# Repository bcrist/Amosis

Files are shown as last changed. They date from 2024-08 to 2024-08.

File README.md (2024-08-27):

# Amosis Keyboard

The Amosis is a 40% split keywell board with a Cirque trackpad built into each side.  The case is 3D printed, and features a keywell shape similar to Kinesis or Dactyl keyboards, except with only three rows.

## Controller
This keyboard uses custom controller firmware written from scratch in Zig, and running on an RP2040.

It does not have runtime-swappable layouts or configuration.  Instead, the keyboard layout, layer switching logic, mouse sensitivity, etc. is baked into the firmware, but updating the firmware is just a matter of holding the BOOT button while pressing the RESET button, then dragging a UF2 file to the RPI USB drive.

All of interesting configuration/layout stuff is handed in the [logic.zig](https://github.com/bcrist/Amosis/blob/main/firmware/logic.zig) file.  It should be relatively easy to customize the layout, though if you want to make behavioral changes, you will likely need to know some Zig.

The default layout is based on [Hands Down Gold](https://sites.google.com/alanreiser.com/handsdown#h.j66p50cw2471).  The exact details can be found [here](https://docs.google.com/spreadsheets/d/1Owf2ERAmP1oHp472hNBu8RwOKwRJ6sjyrHRkhDTo6_Y/edit?usp=sharing).

It would probably be possible to use something like QMK with Amosis controllers, but please don't ask me to help with that; I have no interest and little experience with QMK, ZMK, etc.

## Trackpad
Each side of the keyboard integrates a 40mm Cirque GlidePoint trackpad from a Steam Controller.  While Valve stopped producing Steam Controllers years ago, you can still purchase the trackpads from [Mouser](https://www.mouser.com/c/?marcom=118816186), but you will likely need to make some modifications to make this work:

* There are several sizes available; the Steam Controller uses the largest 40mm size (TM40040), but you could use a smaller one if you adjust the case design.
* The retail Circues offer several options for plastic overlays, but the Steam Controller used custom overlays, so you may need to adjust the case design for your chosen overlay style.
* There are (or were) both SPI and I2C versions available.  The Steam Controller only uses SPI, so you'll need to adjust the firmware if you want to use an I2C version (though I think you can change it just by adding/removing a resistor on the Cirque board).  The SPI versions have part numbers TMxx0xx-2024 while the I2C versions have part numbers TMxx0xx-2023.  At time of writing, it appears Mouser no longer carries the I2C version.
* The Steam Controller uses a customized connector pinout that's different than what's documented in the datasheet for the retail version.  You'll need to adjust the schematic board layout to accomodate this.
* An [Alps Haptic Reactor](https://www.mouser.com/ProductDetail/Alps-Alpine/AFT14A903A) force-feedback element is glued to the back of the Steam Controller version and its power is routed through the same FFC cable.  If you buy this separately, you'll have to figure out how you want to connect it to the board.

## Building

Have the controller boards manufactured using the files in the `kicad/gerbers/left/` and `kicad/gerbers/right` folders.

Ensure dependencies are available on your path:
* [Zig](https://ziglang.org/download/)
* [OpenSCAD](https://openscad.org/downloads.html) (2023.03.18 or newer; scroll down to "Development Snapshots")

Adjust the keymapping and layer logic as you like, then run `zig build`.

3D print a case using `zig-out/bin/left.stl` and `zig-out/bin/right.stl`.

Flash the `zig-out/bin/firmware.uf2` and to both controllers (the same file can be used for both sides because the firmware will detect which side it is at boot).

### Wiring
The 3 row signals are driven to 3.3V when scanning a row, and 0V when not scanning that row.
The 7 column signals are read as inputs with weak pull-downs, and treat a high value as indicating that a switch is pressed.
Therefore, there are 2 possible ways to wire the diode/switch matrix that will work:
* Diodes between the row signals and the switches, with a common anode for each row.
* Diodes between the column signals and the switches, with a common cathode for each column.

Note the line on diode packages indicates the cathode side.
Also note while the schematics list a schottky diode part number, any general purpose diodes will work fine for the matrix, e.g. 1N914/1N4148, 1N4001, etc.

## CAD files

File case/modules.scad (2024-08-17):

module edge_sphere() {
    sphere(edge_radius);
}

module edge_capsule() {
    hull() {
        translate([0, 0, -edge_radius]) sphere(edge_radius);
        translate([0, 0, -plate_thickness + edge_radius]) sphere(edge_radius);
    }
}

module cherry_mx_plate(width_u = 1, height_u = 1) {
    u = 19.05;
    width = width_u * u - switch_plate_inset;
    height = height_u * u - switch_plate_inset;
    clip_thickness = 1.5;
    clip_inset = 0.25;
    clip_width = 5;
    hole_size = 14.2;
    nub_length = 3.5;
    nub_radius = 0.8;

    horiz_edge();
    rotate([0, 0, 180]) horiz_edge();
    
    vert_edge();
    rotate([0, 0, 180]) vert_edge();

    children();
    
    module vert_edge() {
        translate([-width/2, -height/2]) {
            hull() {
                translate([0, 0, -edge_radius]) sphere(edge_radius);
                translate([0, 0, -plate_thickness + edge_radius]) sphere(edge_radius);
                translate([width, 0, -edge_radius]) sphere(edge_radius);
                translate([width, 0, -plate_thickness + edge_radius]) sphere(edge_radius);
            }
            translate([0, 0, -clip_thickness]) cube([width, height/2 - hole_size/2, clip_thickness]);
            translate([0, 0, -plate_thickness]) {
                cube([width, height/2 - hole_size/2 - clip_inset, plate_thickness]);
                cube([width/2 - clip_width/2, height/2 - hole_size/2, plate_thickness]);
                translate([width/2 + clip_width/2, 0]) cube([width/2 - clip_width/2, height/2 - hole_size/2, plate_thickness]);
            }
        }
    }
    
    module horiz_edge() {
        translate([-width/2, -height/2]) {
            hull() {
                translate([0, 0, -edge_radius]) sphere(edge_radius);
                translate([0, 0, -plate_thickness + edge_radius]) sphere(edge_radius);
                translate([0, height, -edge_radius]) sphere(edge_radius);
                translate([0, height, -plate_thickness + edge_radius]) sphere(edge_radius);
            }
            translate([0, 0, -plate_thickness]) cube([width/2 - hole_size/2, height, plate_thickness]);
        }
        // nub
        translate([0, 0, -plate_thickness]) hull() {
            translate([-hole_size/2, 0, plate_thickness/2]) cube([0.01, nub_length, plate_thickness], center=true);
            translate([-hole_size/2, 0, nub_radius]) rotate([90, 0, 0]) cylinder(nub_length, nub_radius, nub_radius, center=true);
        }
    }
}

module cherry_mx() {
    stem_height = 4;
    stem_thickness_x = 1.35;
    stem_thickness_y = 1.15;
    stem_width = 4.5;

    stem_base_width = 7.2;
    stem_base_height = 5.6;
    stem_base_offset = 0.4;

    cover_top = 10.2;
    cover_bottom = 14.6;
    cover_height = 5.3;

    foot_height = 0.8;
    foot_width = 15.6;

    base = 14;
    base_height = 5.5;
    base_taper = 1;
    plate_height = 2.2;

    translate([0, 0, cover_height + foot_height + stem_base_offset]) {
        children();
    }

    translate([0, 0, stem_height + cover_height + foot_height])
    {
        color("cyan"){
            translate([0, 0, -stem_height / 2]) {
                cube([stem_thickness_x, stem_width, stem_height], center=true);
                cube([stem_width, stem_thickness_y, stem_height], center=true);
            }
            translate([0, 0, -stem_height - 1 + stem_base_offset]) {
                cube([stem_base_width, stem_base_height, 2], center=true);
            }
        }
        
        color("grey") translate([0, 0, -stem_height]) {		
            hull(){
                cube([cover_top, cover_top, 0.1], center=true);
                translate([0, 0, -cover_height]) cube([cover_bottom, cover_bottom, 0.1], center=true);
            }
            
            translate([0, 0, -cover_height]) {
                hull(){
                    translate([0, 0, -plate_height/2]) cube([base, base, plate_height], center=true);
                    translate([0, 0, -base_height]) cube([base - base_taper, base - base_taper, 0.1], center=true);
                }

                translate([0, 0, -foot_height/2]) cube([foot_width, foot_width, foot_height], center=true);
                translate([0, 0, -foot_height]) difference(){
                    hull(){
                        translate([0, 0, -1.4]) cube([3.5, 14, 0.1], center=true);
                        translate([0, 0, -2])   cube([3.5, 14.75, 0.1], center=true);
                        translate([0, 0, -2.5]) cube([3.5, 14, 0.1], center=true);
                    }
                    translate([0, 0, -1.5]) cube([2, 20, 4], center=true);
                }
            }
        }
    }
}

module keycap_sa(raw_row = 3, width_u = 1, height_u = 1) {
    row = 3 - abs(3 - raw_row);
    base_height = 12.6;
    sa_radius = 33.3;
    row_offset = 4;
    dy = row_offset * (3 - raw_row);
    u = 19.05;
    width = width_u * u;
    height = height_u * u;
    color("#99f") translate([0, -dy, -row + 1]) difference() {
        intersection() {
            union() {
                translate([sa_radius - width/2, height/2 + dy, 0])   rotate([90,0,0]) cylinder(h = height, r = sa_radius);
                translate([sa_radius + width/2, dy, sa_radius/2]) cube([width*2, height, sa_radius], center=true);
            }
            union() {
                translate([-width/2, sa_radius - height/2 + dy, 0]) rotate([90,0,90])  cylinder(h = width, r = sa_radius);
                translate([0, sa_radius + height/2 + dy, sa_radius/2]) cube([width, height*2, sa_radius], center=true);
            }
            union() {
                translate([-sa_radius + width/2, -height/2 + dy, 0])   rotate([90,0,180]) cylinder(h = height, r = sa_radius);
                translate([-sa_radius - width/2, dy, sa_radius/2]) cube([width*2, height, sa_radius], center=true);
            }
            union() {
                translate([width/2, -sa_radius + height/2 + dy, 0]) rotate([90,0,270])  cylinder(h = width, r = sa_radius);
                translate([0, -sa_radius - height/2 + dy, sa_radius/2]) cube([width, height*2, sa_radius], center=true);
            }
        }
        scale([width_u, height_u, 1]) {
            translate([0, 0, base_height + sa_radius]) sphere(r = sa_radius);
            translate([0, 0, -sa_radius + row - 1]) cube(sa_radius * 2, center=true);
        }
    }
}

cirque_outer_diameter = 42.8;
cirque_inner_diameter = 35;
cirque_inset_depth = 2;
cirque_border_width = 1;
cirque_base_thickness = 30;
cirque_edge_radius = 8;

module half_cirque_plate() {
    total_depth = cirque_base_thickness + cirque_inset_depth;
    outer_radius = cirque_outer_diameter / 2;
    
    translate([0, 0, -total_depth]) {
        intersection() {
            mask_side_length = 2 * (outer_radius + cirque_border_width + cirque_edge_radius);
            translate([0, mask_side_length/2, 0]) cube([mask_side_length, mask_side_length, total_depth * 2], center = true);
            minkowski() {
                cylinder(h = total_depth - cirque_edge_radius, r = outer_radius + cirque_border_width, $fn = 180);
                sphere(cirque_edge_radius, $fn = 90);
            }
        }
    }
}

module cirque_plate() {
    total_depth = cirque_base_thickness + cirque_inset_depth;
    outer_radius = cirque_outer_diameter / 2;
    
    translate([0, 0, -total_depth]) {
        minkowski() {
            cylinder(h = total_depth - cirque_edge_radius, r = outer_radius + cirque_border_width, $fn = 180);
            sphere(cirque_edge_radius, $fn = 90);
        }
    }
}

module cirque_plate_holes() {
    total_depth = cirque_base_thickness + cirque_inset_depth;
    outer_radius = cirque_outer_diameter / 2;
    inner_radius = cirque_inner_diameter / 2;
    
    translate([0, 0, -total_depth]) {
        cylinder(h = 3*total_depth, r = inner_radius, center = true);
        translate([0, 0, cirque_base_thickness]) cylinder(h = total_depth, r = outer_radius, $fn = 180);
    }
}

module cable_guide() {
    minkowski() {
        cube([1, 40, 10], center=true);
        sphere(5);
    }
}

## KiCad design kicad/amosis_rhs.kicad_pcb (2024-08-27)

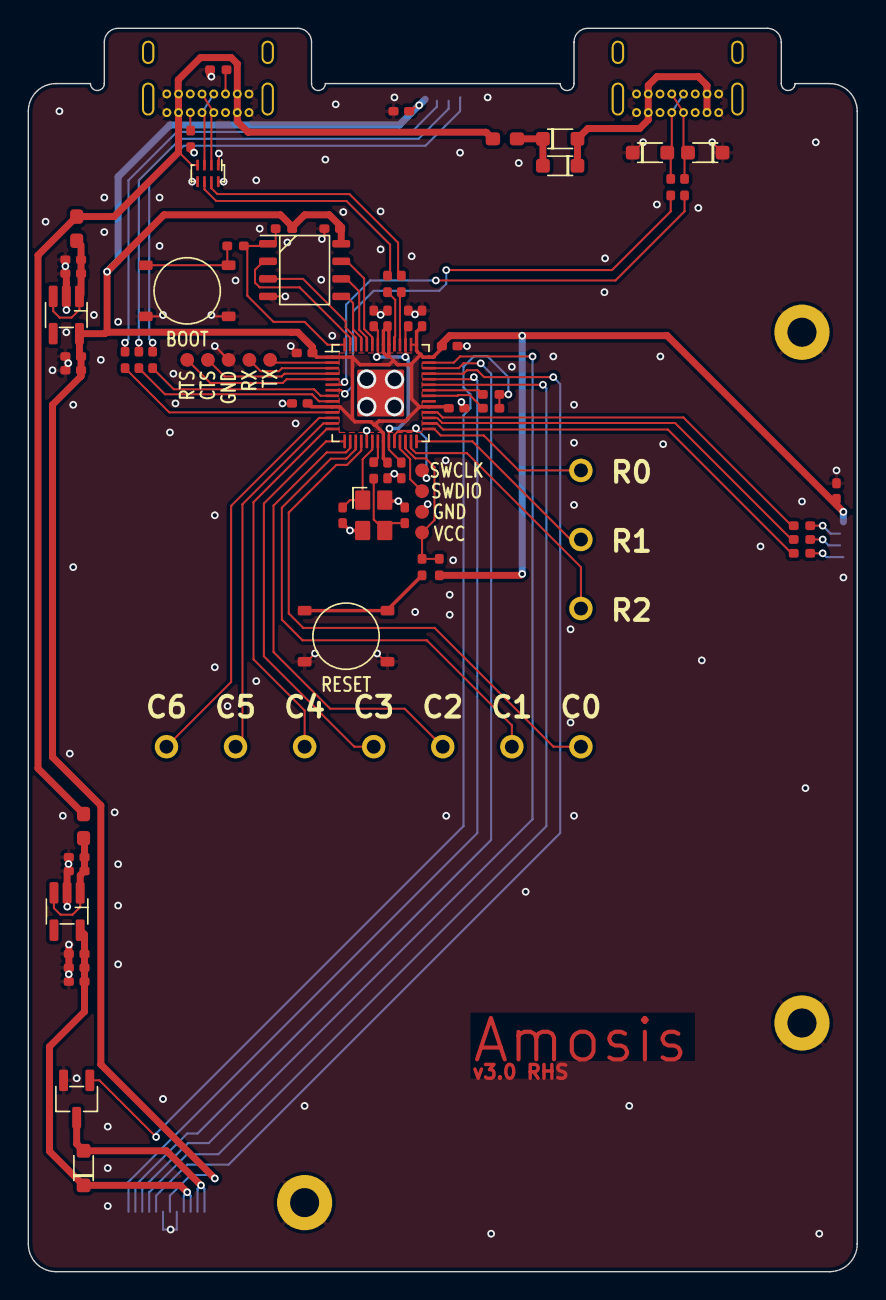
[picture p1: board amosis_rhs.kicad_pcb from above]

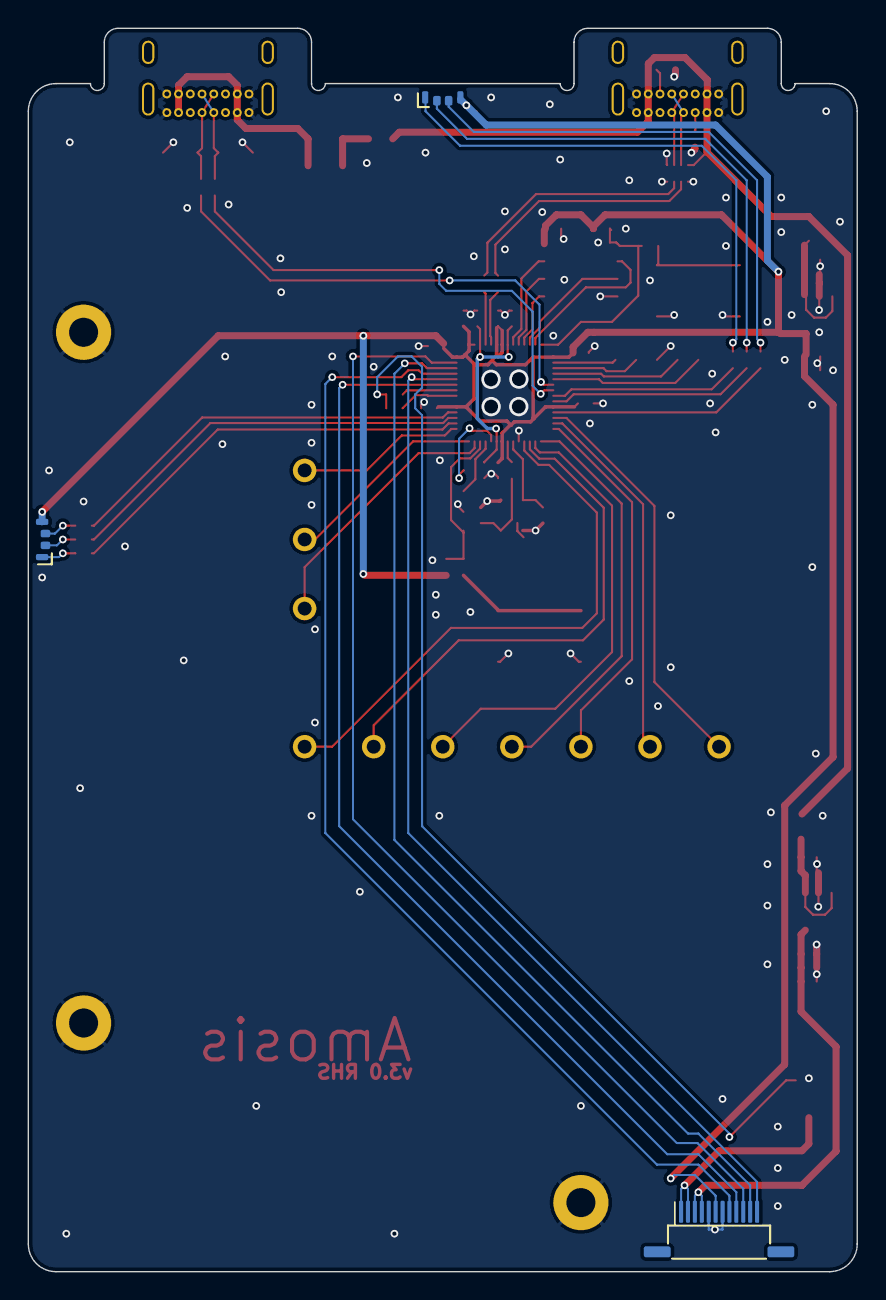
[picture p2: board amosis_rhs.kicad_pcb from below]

Board: 2 copper layers, 60.0 x 90.0 mm, 87 parts (5 on the bottom side), 70 nets.

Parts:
C1, C4, C5, C8, C10, C17: 1; C_0402
C2, C3, C6, C7, C11, C12, C13, C14, C15, C16, C18, C19, C20, C23, C24: 0.1; C_0402
C9: 10; C_0402
C21, C22: 14p; C_0402
COL_{0}1: COL_{0}; PinHeader_1x01
COL_{1}1: COL_{1}; PinHeader_1x01
COL_{2}1: COL_{2}; PinHeader_1x01
COL_{3}1: COL_{3}; PinHeader_1x01
COL_{4}1: COL_{4}; PinHeader_1x01
COL_{5}1: COL_{5}; PinHeader_1x01
COL_{6}1: ROW_{0}; PinHeader_1x01
D22, D23: CUS520; SOD-323
D24: ECMF02-4CMX8; DFN-8-2.5x1.2-P0.45
D25, D26: DESD5V0U1BA; SOD-323
D27, D28: LED_BGRA; Harvatek-B3233GBR-20
D29: MMBD914LT1; SOD-323
FB1, FB2, FB3: PE-0603FB121ST; L_0603
J1, J2: USB-C-16; USB_GCT_USB4085-FG-A
J3: VALVE; FFC_GCT_FFC2B28-12-G
M1, M2, M3: GND; MountingHole_M2_Pad
Q1: MMBT3904; SOT-23
R1, R13: 10K; R_0402
R2, R12, R16: 1K; R_0402
R3, R4: 50; R_0402
R5, R8: 27.4; R_0402
R6, R7, R18: 5.1K; R_0402
R9, R14: 120; R_0402
R10, R11, R15, R17: 10; R_0402
R19: 2.2K; R_0402
ROW_{0}1: ROW_{1}; PinHeader_1x01
ROW_{1}1: ROW_{2}; PinHeader_1x01
ROW_{2}1: ROW_{3}; PinHeader_1x01
SW22: RESET; SW_CK_PTS526
SW23: BOOT; SW_CK_PTS526
U1: MIC5504-3.3YM5; SOT-23-5
U2: MIC5504-2.5YM5; SOT-23-5
U3: RP2040; QFN-56-EP-7x7-P0.4
U4: ZD25Q80CT; SOP-8-4.9x3.9-P1.27
X1: RH100-12.000-12-1010-X-TR-NS2
tCTS1: CTS; TestPoint
tGND1, tGND2: GND; TestPoint
tRTS1: RTS; TestPoint
tRUN1: VCC; TestPoint
tRX1: RX; TestPoint
tSWCLK1: SWCLK; TestPoint
tSWDIO1: SWDIO; TestPoint
tTX1: TX; TestPoint

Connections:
+2V5: C7.1, C8.1, C9.1, D29.1 (K), J3.3, J3.4, U2.5 (VOUT)
/COL_{0}: COL_{0}1.1, U3.18 (P15)
/COL_{1}: COL_{1}1.1, U3.17 (P14)
/COL_{2}: COL_{2}1.1, U3.16 (P13)
/COL_{3}: COL_{3}1.1, U3.15 (P12)
/COL_{4}: COL_{4}1.1, U3.14 (P11)
/COL_{5}: COL_{5}1.1, U3.13 (P10)
/COL_{6}: COL_{6}1.1, U3.12 (P9)
/DR: J3.9, U3.37 (P25)
/LINK_RX: R3.2, U3.7 (P5)
/LINK_TX: R4.1, U3.6 (P4)
/MISO: J3.11, U3.40 (P28/A2)
/MOSI: J3.8, U3.39 (P27/A1)
/ROW_{0}: ROW_{0}1.1, U3.29 (P18)
/ROW_{1}: ROW_{1}1.1, U3.28 (P17)
/ROW_{2}: ROW_{2}1.1, U3.27 (P16)
/SCLK: J3.12, U3.38 (P26/A0)
/SS: J3.10, U3.41 (P29/A3)
GND: C1.2, C2.2, C3.2, C4.2, C5.2, C6.2, C7.2, C8.2, C9.2, C10.2, C11.2, C12.2, C13.2, C14.2, C15.2, C16.2, C17.2, C18.2, C19.2, C20.2, C21.2, C22.2, C23.2, C24.2, D24.1, D24.5, D24.8, D25.1 (A1), D26.1 (A1), J1.A1 (GND), J1.A12 (GND), J1.B1 (GND), J1.B12 (GND), J2.A1 (GND), J2.A12 (GND), J2.B1 (GND), J2.B12 (GND), J3.5, J3.7, M1.1, M2.1, M3.1, Q1.2 (E), R6.2, R7.2, SW22.3, SW22.4, SW23.3, SW23.4, U1.2 (GND), U2.2 (GND), U3.19 (GND), U3.EP (GND), U4.4 (GND), X1.2, X1.4, tGND1.1, tGND2.1
unnamed: C22.1, R12.2, X1.3
unnamed: D22.2 (A), D23.1 (K), FB3.2
unnamed: D22.1 (K), D23.2 (A), J1.A4 (V_{BUS}), J1.A9 (V_{BUS}), J1.B4 (V_{BUS}), J1.B9 (V_{BUS})
unnamed: D24.6, R5.2
unnamed: D24.7, R8.1
unnamed: D25.2 (A2), J1.A6 (D+1), J1.B6 (D+2), R3.1
unnamed: D26.2 (A2), J1.A7 (D-1), J1.B7 (D-2), R4.2
unnamed: D27.1 (BK), R9.2
unnamed: D27.2 (GK), R10.2
unnamed: D27.3 (RK), R11.2
unnamed: D28.1 (BK), R14.2
unnamed: D28.2 (GK), R15.2
unnamed: D28.3 (RK), R17.2
unnamed: D29.2 (A), J3.1, J3.2, Q1.3 (C)
unnamed: J2.A5 (CC1), R6.1
unnamed: J2.B5 (CC2), R7.1
unnamed: D24.3, J2.A6 (D+1), J2.B6 (D+2)
unnamed: D24.2, J2.A7 (D-1), J2.B7 (D-2)
unnamed: Q1.1 (B), R18.2, R19.2
unnamed: R2.2, SW22.1, SW22.2
unnamed: R16.2, SW23.1, SW23.2
unnamed: C1.1, C2.1, FB1.2, U1.1 (VIN), U1.3 (EN)
unnamed: C5.1, C6.1, FB2.2, U2.1 (VIN), U2.3 (EN)
unnamed: U3.2 (P0), tTX1.1
unnamed: U3.3 (P1), tRX1.1
unnamed: U3.4 (P2), tCTS1.1
unnamed: U3.5 (P3), tRTS1.1
unnamed: R9.1, U3.8 (P6)
unnamed: R10.1, U3.9 (P7)
unnamed: R11.1, U3.11 (P8)
unnamed: R14.1, U3.30 (P19)
unnamed: R15.1, U3.31 (P20)
unnamed: R17.1, U3.32 (P21)
unnamed: R18.1, U3.35 (P23)
unnamed: R19.1, U3.36 (P24)
unnamed: U3.52 (QSPI_{CLK}), U4.6 (CLK)
unnamed: U3.53 (QSPI_{SD0}), U4.5 (D0)
unnamed: U3.55 (QSPI_{SD1}), U4.2 (D1)
unnamed: U3.54 (QSPI_{SD2}), U4.3 (D2)
unnamed: U3.51 (QSPI_{SD3}), U4.7 (D3)
unnamed: R13.2, R16.1, U3.56 (QSPI_{~SS}), U4.1 (~CS)
unnamed: R1.2, R2.1, U3.26 (RUN), tRUN1.1
unnamed: U3.24 (SWCLK), tSWCLK1.1
unnamed: U3.25 (SWDIO), tSWDIO1.1
unnamed: R5.1, U3.47 (USB_{D+})
unnamed: R8.2, U3.46 (USB_{D-})
unnamed: C17.1, C18.1, C19.1, U3.23 (VDD_{D}), U3.45 (VREG_{OUT}), U3.50 (VDD_{D})
unnamed: C21.1, U3.20 (X_{IN}), X1.1
unnamed: R12.1, U3.21 (X_{OUT})
VBUS: D24.4, FB1.1, FB2.1, FB3.1, J2.A4 (V_{BUS}), J2.A9 (V_{BUS}), J2.B4 (V_{BUS}), J2.B9 (V_{BUS})
VCC: C3.1, C4.1, C10.1, C11.1, C12.1, C13.1, C14.1, C15.1, C16.1, C20.1, C23.1, C24.1, D27.4 (A), D28.4 (A), J3.6, R1.1, R13.1, U1.5 (VOUT), U3.1 (VDD_{IO}), U3.10 (VDD_{IO}), U3.22 (VDD_{IO}), U3.33 (VDD_{IO}), U3.42 (VDD_{IO}), U3.43 (VDD_{ADC}), U3.44 (VREG_{IN}), U3.48 (VDD_{USB}), U3.49 (VDD_{IO}), U4.8 (VCC)

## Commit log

2024-08-17 v3 (WIP)
    [amosis.kicad_pcb, amosis.kicad_sch, amosis_rhs.kicad_pcb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]
2024-08-27 logic & fixes
    [amosis.kicad_pcb, amosis.kicad_sch, amosis_rhs.kicad_pcb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]
2024-08-27 Don't allow changing host location to a side that's not currently connected
